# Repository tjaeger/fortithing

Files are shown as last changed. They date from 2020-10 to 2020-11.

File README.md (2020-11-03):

[Datasheet](/_asset/Datasheet.pdf)

[Schematics](/hardware/FortiThing%20v2.0%20rev.A%20SCHEMATICS.pdf)

[Docu on fortithing.readthedocs.io](https://fortithing.readthedocs.io/en/latest/)

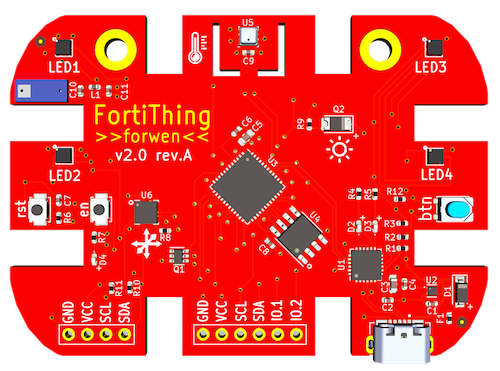
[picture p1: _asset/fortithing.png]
FortiThing


# FortiThing v2 

## Hardware

FortiThing is built around Espressif ESP32 MCU (ESP32-PICO-D4).
2MB integrated Flash, 32/64Mbit external QSPI Memory.

In addition it has a series of actors and sensors. Those are:
* IR/Light Sensor
* 3-Axis Accelerometer
* Temperature, Humidity, barometric pressure
* 4x programmable RGB-LED (LS8822/NS107)
* Capacitive-Touch sensor (back side)
* Tactile Button (front side)
* Exposed I2C Bus
* Exposed IO1/IO2 Pins

ESP32 Details
* Bluetooth
* WIFI (2.4Ghz)
* on-board 3D Antenna
* Dual Core Tensilica MCU
* Micropython, Arduino, native IDF and many more Environments
* 64Mbit QSPI RAM & 2MB integrated Flash

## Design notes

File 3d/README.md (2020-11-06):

This is an OpenSCAD design for a 3D protective case for FortiThing v2.
There is (currently) no lid to the box.

The STL was generated from OpenSCAD. It is provided here for people who can process .scad.

The protective enclosure was successfully printed on an Anet A8, with PLA.

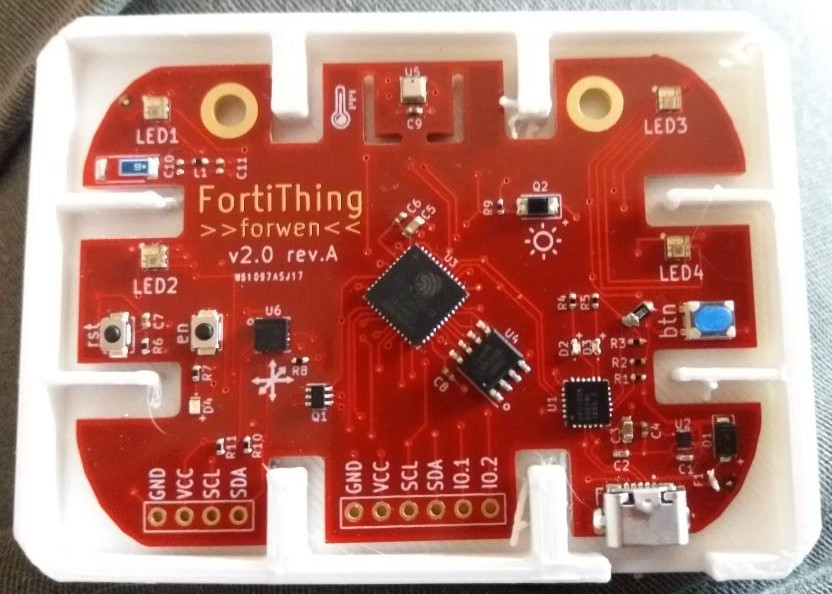
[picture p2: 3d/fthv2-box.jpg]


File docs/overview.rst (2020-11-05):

FortiThing Overview
-----------------------

The FortiThing Documentation Project is a community based documentation effort.
Goal is to document fundamentals, use cases and examples for various cases.
FortiThing is very flexible on how to be programmed, MicroPYTHON,
C++, Arduino/C to name a few.
It has WiFi and Bluetooth connectivity so it can talk to the World.

FortiThing is built to make this "IoT thing" more tangible and to have fun.
I wanted the programmability of a Microcontroller, the ease of Arduino or Python
the power of Internet connectivity - it should have Sensors and Actors. Last but not
least that thing has to be able to blink.

FortiThing is helping interested Audience and geeks to get a grasp on IoT.
It's a "fortified" shaped Microcontroller Platform with Sensors and Actors.

Repository can be found on [Github](https://github.com/tjaeger/fortithing.git)

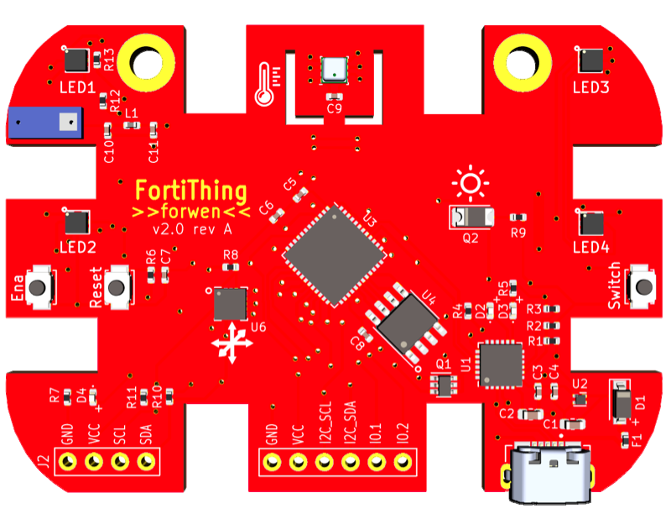
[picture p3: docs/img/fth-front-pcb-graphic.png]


Want to help ?
--------------

If you want to support the Project with contributing a use case or libraries or
apps or even documentation ?

- Developed a Demo for MS Azure integration ?
- Created a cool Demo to show IoT Security with FortiGate ?
- Built something useful with external stuff connected ?
- Missing something in the Docu and want to add ?

Let me know !

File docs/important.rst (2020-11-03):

Important notes
================

FortiThing has been design with care and is tolerant to many circumstances.
However basic measures should be applied and basic rules being followed to avoid damage to both FortiThing or connected Devices.

.. warning::
   It's unlikely you destroy the Hardware "easy" but the external IO nor other ports (eg USB) are ESD protected. It's recommended to apply basic ESD measure to avoid damage. For Example ground yourself (touch Laptop) before touching the board.

.. warning::
   It's unlikely you destroy the Hardware "easy" but the external IO nor other ports (eg USB) are ESD protected. It's recommended to apply basic ESD measure to avoid damage. For Example ground yourself (touch Laptop) before touching the board.

.. warning::
   3.3V Power on IO is directly connected to Main Power net off LDO. There is no Fuse. If you create a short-circuit it may damage the LDO or other components.

.. important::
   The main power (5V from USB) is protected with a PTC Fuse. A short on the board should not damage a connected Laptop.

.. important::
  You should not draw more than 30mA per GPIO from the external connectors as they’re directly connected to MCU. Drawing more may damage the MCU. Treat them as Digital-IO or low-power PWM.

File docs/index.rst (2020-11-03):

==========================================
Welcome to FortiThing Doc's documentation!
==========================================

.. toctree::
   :caption: Intro
   :maxdepth: 2

   important.rst
   overview

.. toctree::
   :caption: Hardware Details
   :maxdepth: 1

   /hwref/hwref
   /hwref/gpio

.. toctree::
   :caption: Getting started
   :maxdepth: 2

   /getstarted/index.rst

.. toctree::
   :caption: Arduino Toolchain
   :maxdepth: 2

   /arduino/arduino.rst

.. toctree::
   :caption: Micropython
   :maxdepth: 2

   /micropython/micropython.rst
   /micropython/firststeps.rst

.. toctree::
   :caption: License
   :maxdepth: 2

   license

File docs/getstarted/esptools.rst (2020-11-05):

Environment/ESPTools
---------------------

It makes sense to install a basic environment for tools like ESPTool, micropython and others. If you only plan to work with Arduino IDE this step can be skipped

# Virtualenv for Python

To not mess up your system Python environment it's recommened to install virtualenv.
Also istall a recent Version of python, 3.7/3.8 [#]_

`Python download from python.org <https://www.python.org/downloads/>`_

`virtualenv download from pypa.io <https://virtualenv.pypa.io/en/latest/installation.html>`_

Footnote 2 [#]_

.. code-block:: bash
   :emphasize-lines: 1, 7

   $ virtualenv -p python3.8 env38
   Running virtualenv with interpreter /Library/Frameworks/Python.framework/Versions/3.8/bin/python3.8
   Also creating executable in /private/tmp/env38/bin/python
   Installing setuptools, pip, wheel...
   done.

   $ source env38/bin/activate
   (env38) $ python -V
   Python 3.8.2

Install ESPTools directly
-------------------------

.. code-block:: bash

   (env38) $ pip install esptools
   [...]
   (env38) $ esptool.py version‚

.. note::

   ESPTools are needed to flash Firmware (unless you use Arduino) to FortiThing. For Example if you need to flash Micropython Firmware.

Install ESPTools in Docker
-------------------------

.. code-block:: bash

$ docker pull espressif/idf:latest
Status: Downloaded newer image for espressif/idf:latest
docker.io/espressif/idf:latest

.. note::

This pulls "latest" IDF. You also can specify a specific Version, see https://hub.docker.com/r/espressif/idf/tags
for available images.

.. [#] Footnote test.
.. [#] Footnote2 test.

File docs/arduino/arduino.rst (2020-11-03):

Arduino
===========

Installation Arduino
------------------------

This chapter still needs to be done. Really.

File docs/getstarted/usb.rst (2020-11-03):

Basic connectivity
-------------------

Typically you'll connect to FortiThing by USB. It uses a CP2102N Chipset for USB->UART which you need to install the VCP drivers for. The CP2102N is a very well supported Chip and provides Drivers for all major OS and also is quick in updates for new OS Releases.

`Download Silabs CP2102N Driver <https://www.silabs.com/products/development-tools/software/usb-to-uart-bridge-vcp-drivers>`_

Once driver has been installed and you plug in FortiThing you should see it recognised:

**Linux/OSX**

.. code-block:: bash 

   $ ls /dev/cu*
   /dev/cu.SLAB_USBtoUART

**Windows**

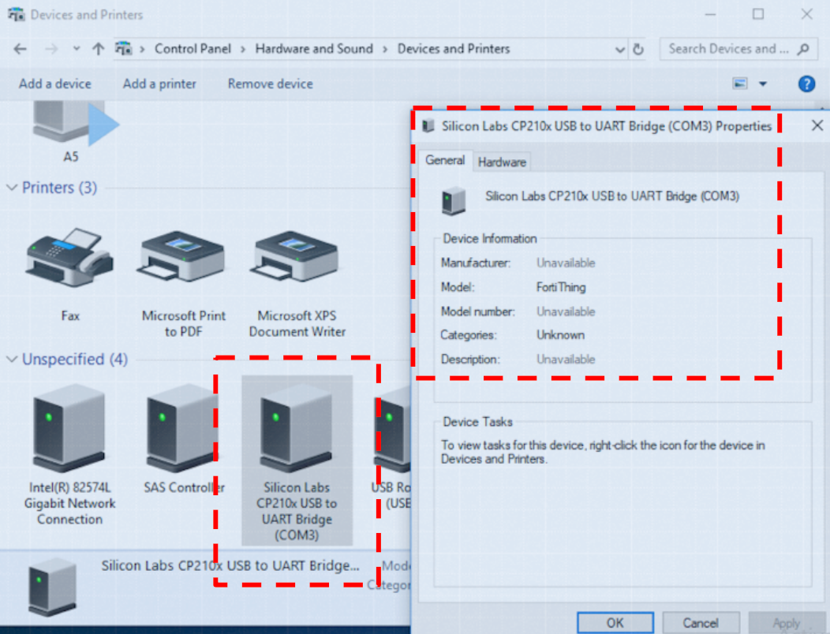
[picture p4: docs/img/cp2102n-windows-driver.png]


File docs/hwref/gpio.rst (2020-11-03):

GPIO Details
===============

This is a graphical overview of the IO Ports which are exposed or being used internally.
It contains the User defined IO Ports as well as the MCU ports for other Services.
eg the MCU ports for I2C-Bus, RGB LED Bus, integrated LED and Switches.

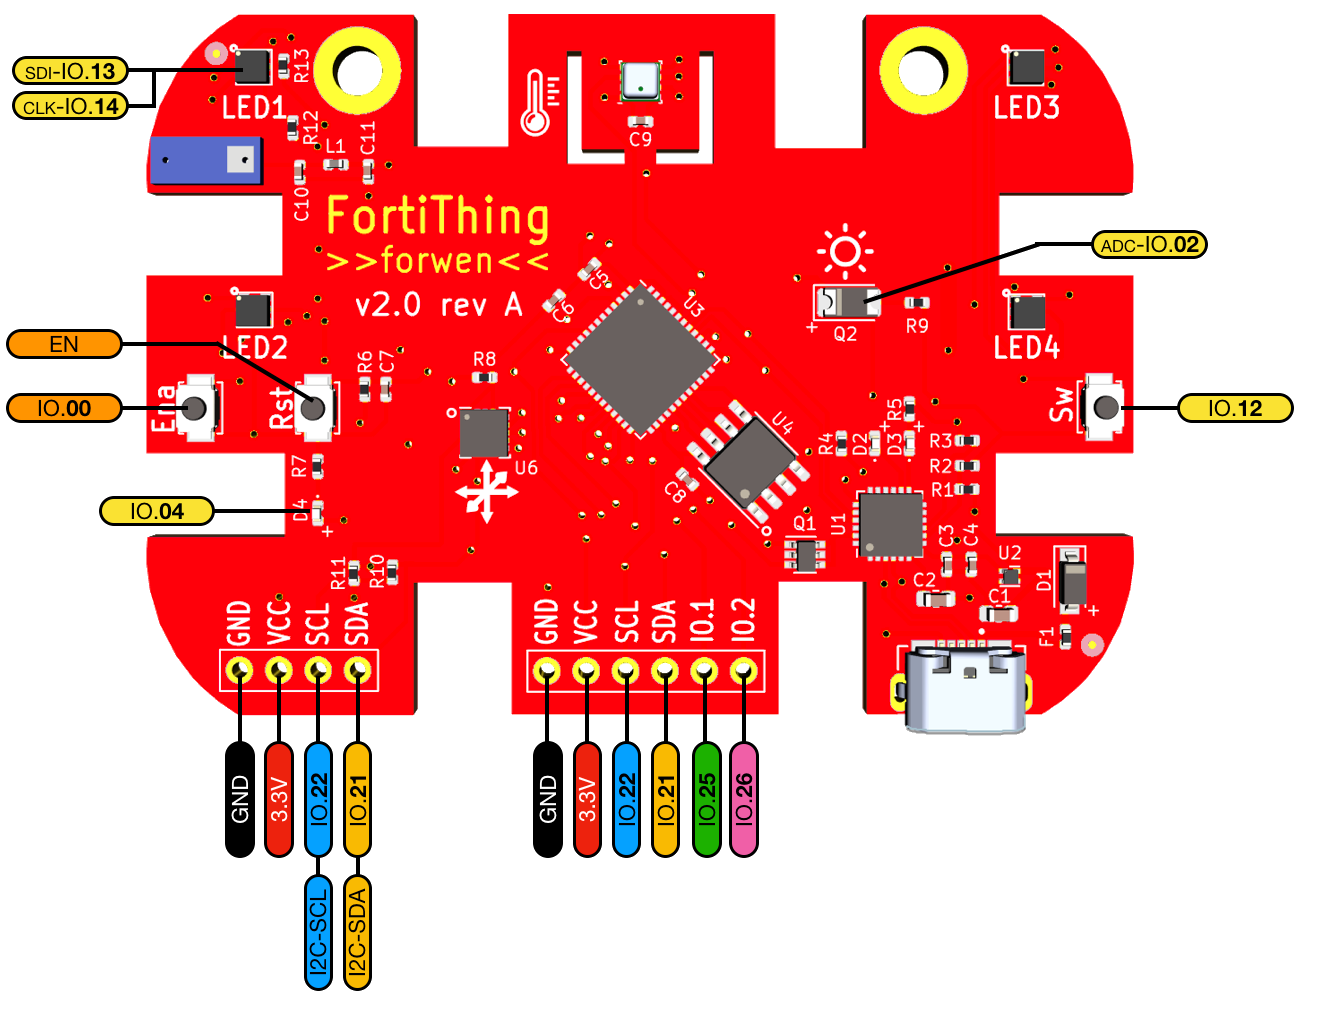
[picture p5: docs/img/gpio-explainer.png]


I2C Bus
-------------

BME280, LISDH30 and optionally OLED Displays are hooked up to a I2C Bus.

Predefined Addresses are:

- BME280, ``0x77``
- LISDH30, ``0x18``
- OLED, typically ``0x3c`` for those ssd1306 OLED

.. note::
   The I2C Bus is internally terminated with 4.7k Ohm. If you hook up external I2C Slaves make sure they don't have another set of pull-up resistors.

External Pin Headers
----------------------

There are 2 rows of external connectors. You can solder Pin Headers to those if you want. They use a standard of 0.54mm pitch and 1mm drill.

# Bottom left section, 4 pins (aka OLED-connector)
# Bottom mid section, 6 pins

The "OLED-connector" has GND/VCC(3.3V) and SCL(I2C), SCA(I2C), exposed. The Layout is typically found on those lower cost "aliexpress" OLED Boards, 0.96"/1.2" OLED and can be directly soldered or via female Headers.

The mid section IO Ports have GND/VCC/SCL/SCA and IO.1/IO.2 exposed. 
IO.1 and IO.2 are connected to Port-25 and Port-26 respectively on the ESP32 Chip.

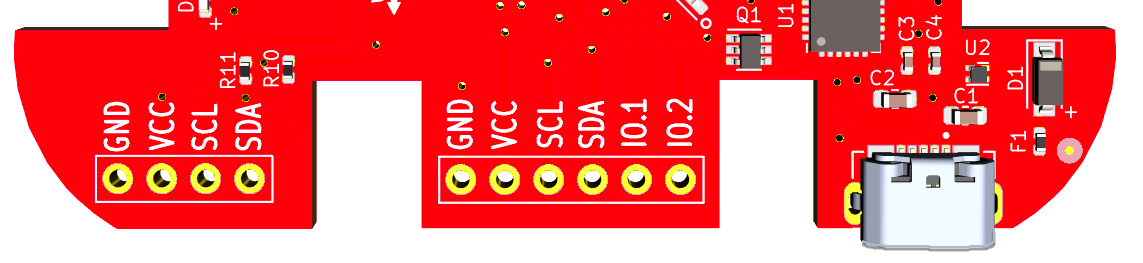
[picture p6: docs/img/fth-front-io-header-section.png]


.. warning::
   The external IO nor other ports (eg USB) are ESD protected. It's recommended to apply basic ESD measure to avoid damage. For Example ground yourself (touch Laptop) before touching the board.

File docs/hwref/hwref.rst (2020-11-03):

FortiThing Hardware Reference
===============================

- **Fortified PCB Layout**
- **65mm x 45mm**

Hardware Design in Detail
-------------------------

**Espressif ESP32 Pico D4 SIP**
   - ESP32 SoC
   - 4MB integrated Flash
   - internal oscillator
   - RF Module
   - 7mm x7mm QFN
   - Dual-Core Tensilica Xtensa LX6 32bit Microprocessor
   - 802.11 b/g/n Wireless 
   - Bluetooth v4.2 (BR/EDR and BT LE support)

**Interfaces:** 
   - UART, SPI, I2C
   - ADC, DAC, PWM

`ESP32 Datasheet <https://www.espressif.com/sites/default/files/documentation/esp32-pico-d4_datasheet_en.pdf>`_

Sensors
-------

**Environmental Sensor**

- ME280 / Bosch 
- Temperature
- relative Humidity
- Barometric Pressure
- I2C/SPI Interface
- 2.5x2.5x0.93mm Package

`Bosch BME280 Datasheet <https://www.bosch-sensortec.com/media/boschsensortec/downloads/datasheets/bst-bme280-ds002.pdf>`_

**Luminosity Sensor**

- IR Spectrum focus
- analog measurement, ADC converts to 16bit output
- peak detection is at 940nm (IR). Range is 730-1100nm

**3-Axis Accelerometer**

- LIS3DHTR / STMicro
- Three axis sensing
- I2C/SPI Interface
- Free-fall detection 
- click/double-click detection
- Interrupt output
- 3x3x1mm LGA-16 Package

`STM LIS3DH Datasheet <https://www.st.com/content/ccc/resource/technical/document/datasheet/3c/ae/50/85/d6/b1/46/fe/CD00274221.pdf/files/CD00274221.pdf/jcr:content/translations/en.CD002742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>`_

Actors
------

**RGB LED**

FortiThing has a total of 4 programmable RGB LEDs.
Utilisig the new NS107S 2020 LED. The LED can be used with the FastLED Library for Example within the Arduino Framework. 

**User progammable Switch**

- There is 1 main programmable tactile switch (SW). The 2nd one is "Ena" - however this has a special function during booting and should be used with care.
- On the backside of the board there is a "touch sensor" (capcitive touch sensor)

**mini LED (Blue)**

Another small (blue) LED is on-board which is user controlled. It can be used as additional LED.

Components Map
--------------

You may find this useful to quickly understand what is located where.
Hic sunt dracones.

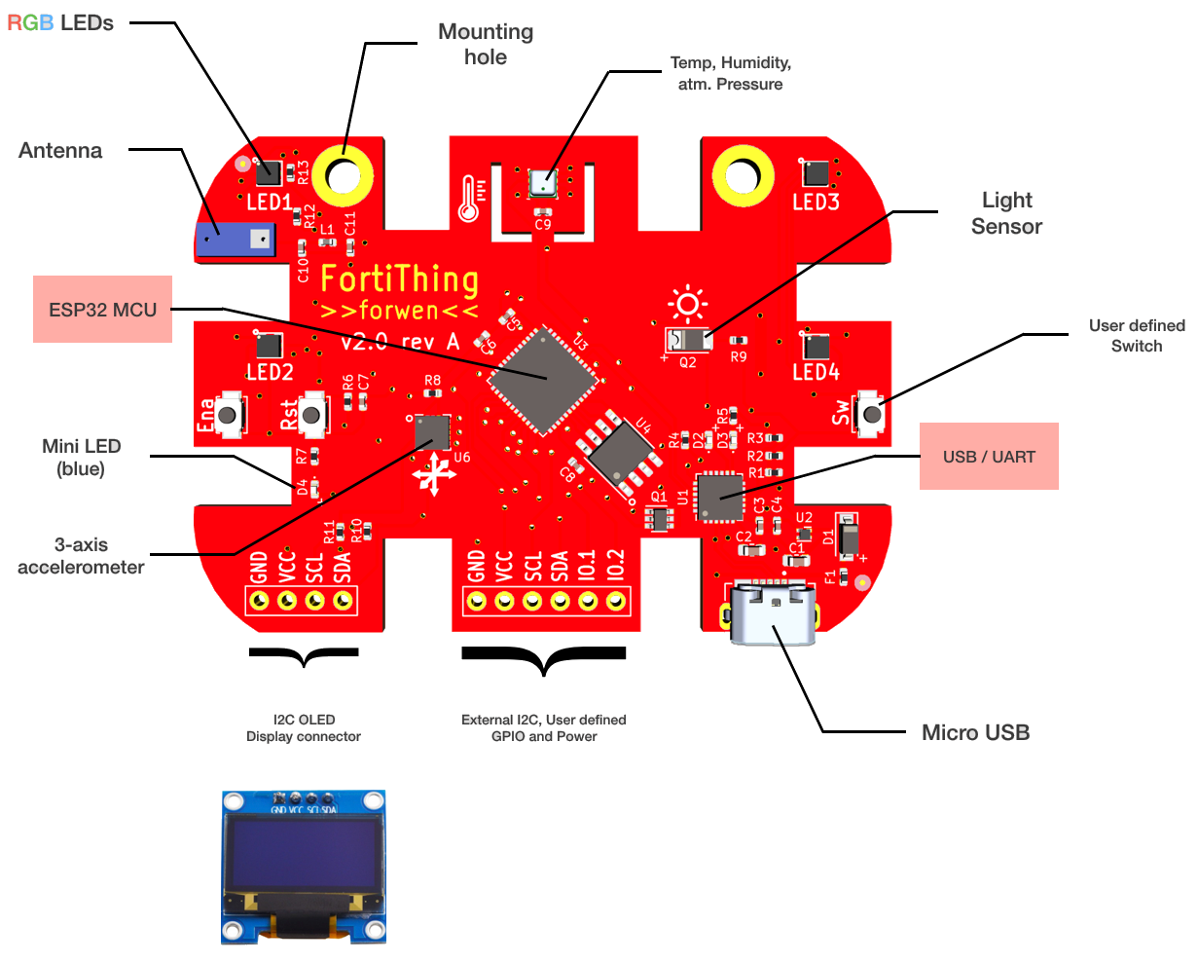
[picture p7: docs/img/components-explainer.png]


FortiThing schematics
---------------------

Schematics :download:`pdf <../img/schematics.pdf>`

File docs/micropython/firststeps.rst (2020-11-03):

Say 'hello' 
------------

.. code-block:: bash 

   (ENV38) $ rshell -p /dev/cu.SLAB_USBtoUART
   > repl
   Entering REPL. Use Control-X to exit.
   repl_serial_to_stdout dev = <rshell.main.DeviceSerial object at 0x102c7e908>>
   >>> help()
   [...]
   >>> print ("Hello FortiThing!")
   Hello FortiThing!

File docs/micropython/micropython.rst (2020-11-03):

MicroPYTHON
===========

.. note:: 

   This assumes you have a virtualenv/Python and ESPTools installed and you are within a virtualenv environment. 

Tools Installation
------------------

Please install some tools to interact with Micropython once installed.
If using ``virtualenv`` make sure you perform this from within.

.. code-block:: bash 

   (ENV38) $ pip3 install rshell 

More Infos on rshell, visit  
`rshell on github <https://github.com/dhylands/rshell>`_

Verify Installation

.. code-block:: bash 

   (ENV38) $ rshell --version

Flashing Micropython 
--------------------

Download Micropython from https://micropython.org/download 
for the ESP32 Platform (GENERIC).
`Github Link for Source and Docs  <https://github.com/micropython/micropython>`_

At the time of writing this is `Micropython 1.12 <https://micropython.org/resources/firmware/esp32-idf3-20191220-v1.12.bin>`_

Flash the downloaded Micropython Firmware to FortiThing:

.. code-block:: bash 

   (ENV38) $ esptool.py --chip esp32 --port /dev/ttyUSB0 --baud 460800 --erase-all write_flash -z 0x1000 esp32-idf3-20191220-v1.12.bin

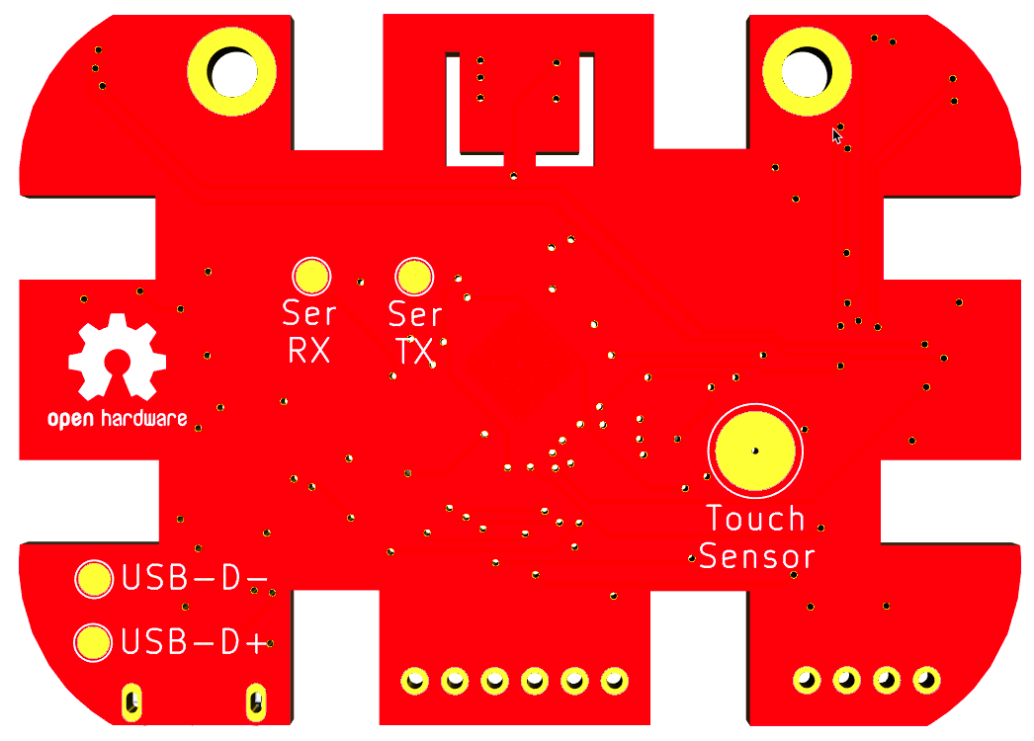
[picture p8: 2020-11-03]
docs/img/fth-back-pcb-graphic.png

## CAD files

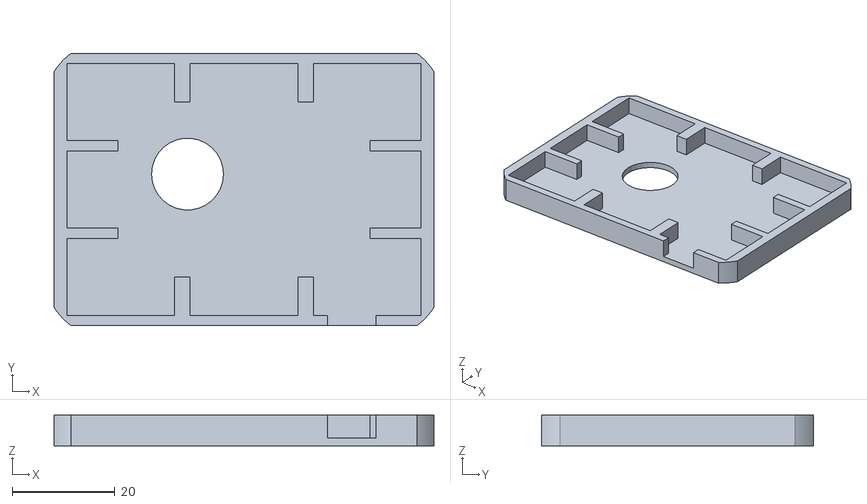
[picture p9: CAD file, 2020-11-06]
3d/fortithing-v2.stl
74.0 x 53.0 x 6.00

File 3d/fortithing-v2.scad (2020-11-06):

// size of the PCB - the +x are for printing margins
fth_length=68+2; 
fth_width=48+1;

// size of the 3D box
box_x = fth_length + 4;
box_y = fth_width + 4;
box_z = 6;


// it's a cube from which we remove 9 identical smaller cubes "noeuds"
// and one central cube.
difference() {
    cube([box_x, box_y, box_z], true);
    noeuds();
    central();
    usbAlim();
    touchSensor();
    roundedCorners();
}

// the PCB roughly has 9 cubes (3x3) which are joined together
module noeuds() {
    for (i = [-24:24:25 ]) {
        for (j = [-17: 17: 17] ) {
            translate([i, j, 1])  cube([18+3,12+3, box_z-1], true);
        }
    }
}

module central() {
    // cube central
    translate([0,0,1]) cube([45+4,30+4,box_z-1], true);   
}

// removes space for the USB power
module usbAlim() {
    color("red") translate([21, -20, 1]) cube([9.5,15, box_z-1], true);
}

// removes space to be able to access the touch sensor behind the PCB
module touchSensor() {
    color("blue") translate([-11, 3, -box_z]) linear_extrude(height=box_z+10) circle(r=7, $fn=30);
}

// just for a nicer look
module roundedCorners() {
    difference() {
        cube([box_x+5,box_y+5,box_z+10], true);
        
        for (i=[-26:52:32]) {
            for (j= [-16:32:25]) {
                translate([i, j,-1]) cylinder(h=box_z+20, r=13, $fn=300, center=true);
            }
        }
        cube([54+3, 52+3, box_z+20], center=true);
        cube([72+3, 32+3, box_z+20], center=true);

    }
}

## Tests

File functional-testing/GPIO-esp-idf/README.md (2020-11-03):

# GPIO tests with esp-idf SDK

The esp-idf SDK from Espressif allow you to go deeper with the ESP32. The code is low level and allow you to control everything in the chip. The drawback is it's slightly more complex than using the Arduino IDE.

## The environment
First, setup the SDK under your favourite OS: [Link to the Espressif web site](https://docs.espressif.com/projects/esp-idf/en/latest/esp32/get-started/index.html)
Tested successfully under Linux and Windows with the Fortithing. Even with VM in Virtualbox plus USB passthrough to flash the device.

## Your first own code
The idea is to start from the `hello_world` from [step 5](https://docs.espressif.com/projects/esp-idf/en/latest/esp32/get-started/index.html#step-5-start-a-project). 
Copy again the template and copy the GPIO.c + CMakeLists.txt files in the folder `main`.
To use the full flash, change the default size: run `idf.py menuconfig` go to `Serial flasher config` and set the `Flash size` to `4 MB`.
Compile and flash the board and that's it.

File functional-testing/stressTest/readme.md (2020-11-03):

# StressTest app for the Fortithing board

The goal of the project is to test during hours and days the board to validate the hardware.

## How it works
The board boot, hook on the local 2.4GHZ WPA/WPA2 Wifi and get it's IP from the DHCP server.
The board send to the server, via a GET request, the asked sensor values by the server. From the server's reply, the board keep the next sensor to send, shift the 4 RGB LED and pause for 1 second.

## Deploy it

### The board
Before flashing the board, 3 steps are needed:
 - Install the lib: FastLED, Adafruit LIS3DH, Adafruit BMP280 Library (and their dependencies)
 - Modify the 4 #define at the beginning of stressTestFortithing.ino file to setup your Wifi and server settings
 - Patch the Adafruit BMP280 lib to read correctly the BMP280 sensor:
Open this file https://github.com/adafruit/Adafruit_BMP280_Library/blob/master/Adafruit_BMP280.cpp
comment those 2 lines:               
 99:   if (read8(BMP280_REGISTER_CHIPID) != chipid)             
100:    return false;                

### The server
PHP need to be installed, create a folder "file" at the root of the server, copy file.php and do the corresponding setting asked for stressTestFortithing.ino.
Do not forget to set the folder writeable for the PHP code.
2 files are generated server side, in CSV format, with the content of the accelerometer and temperature sensors. So you can check the data in a worksheet by graph them and see if everything is accurate.

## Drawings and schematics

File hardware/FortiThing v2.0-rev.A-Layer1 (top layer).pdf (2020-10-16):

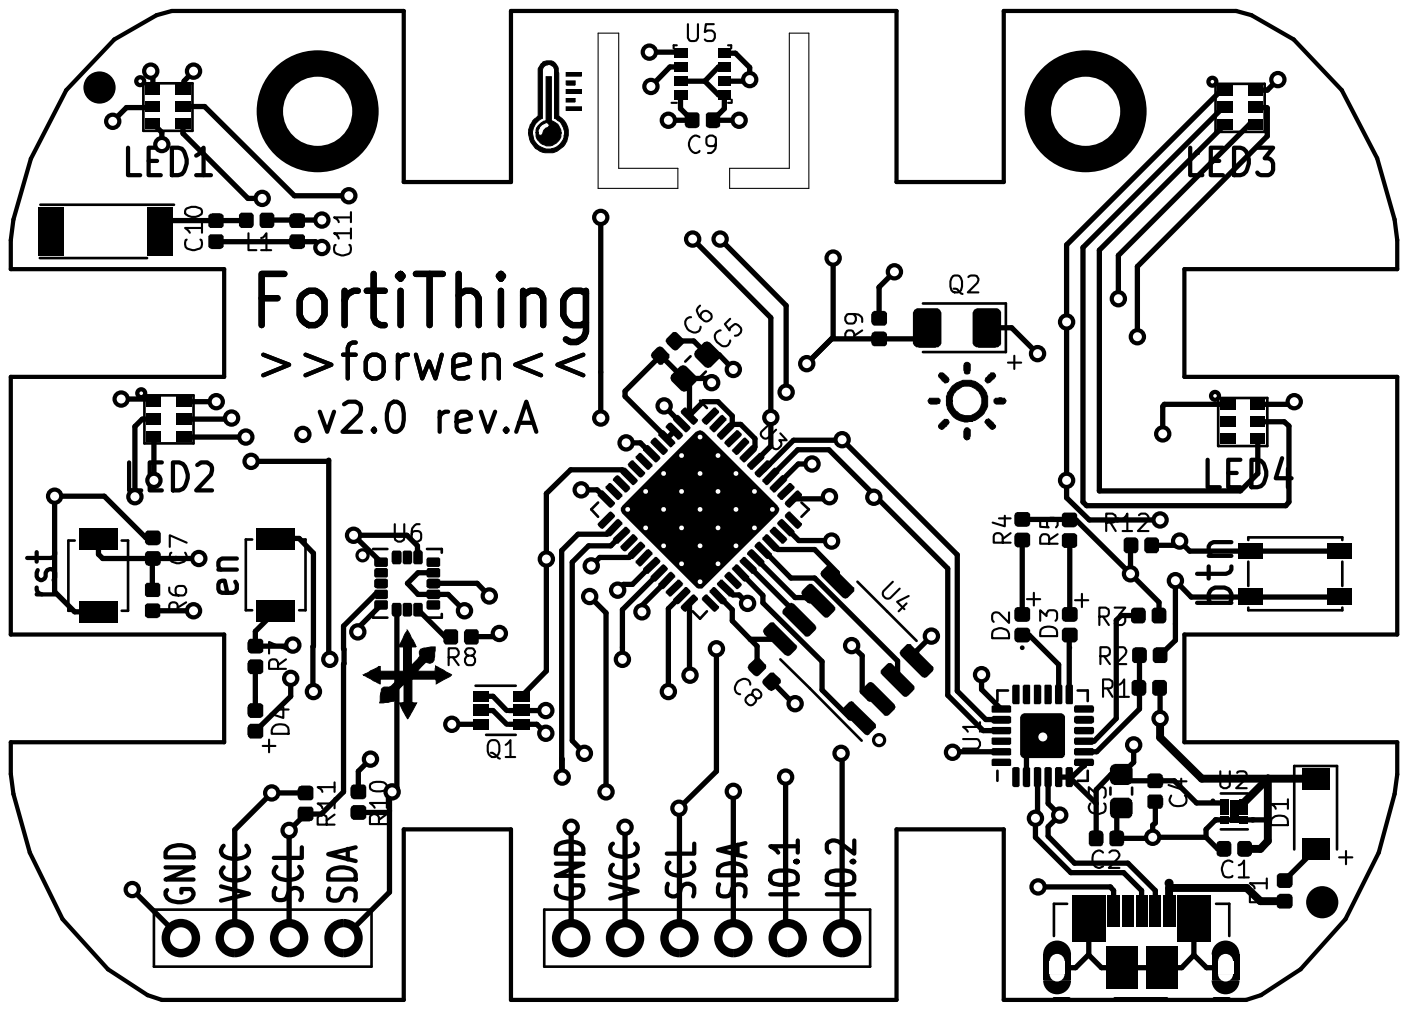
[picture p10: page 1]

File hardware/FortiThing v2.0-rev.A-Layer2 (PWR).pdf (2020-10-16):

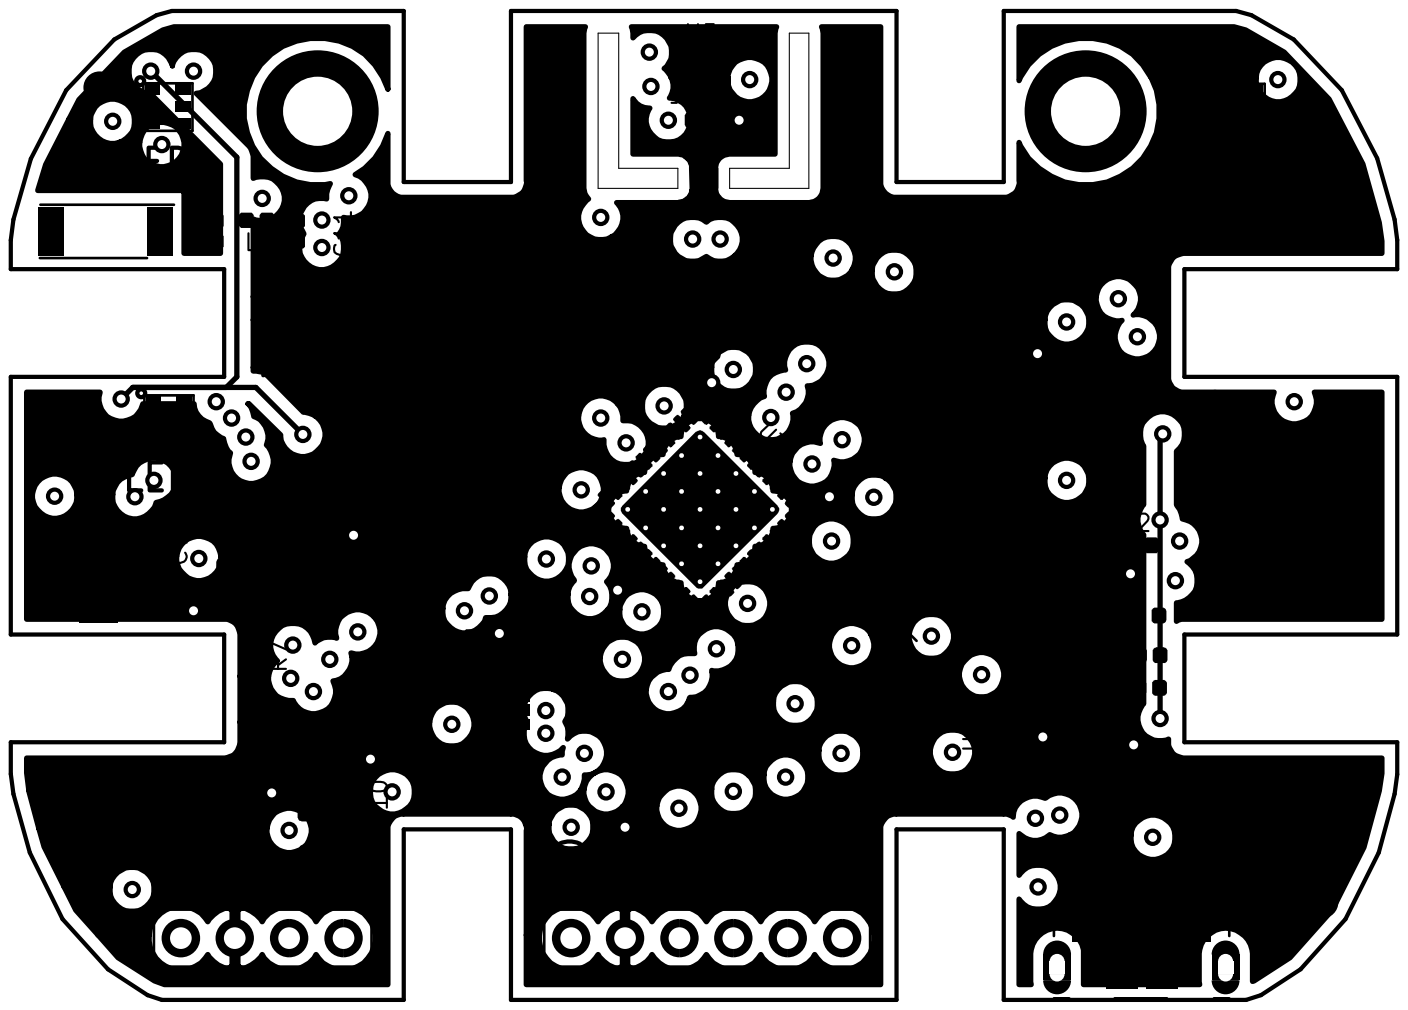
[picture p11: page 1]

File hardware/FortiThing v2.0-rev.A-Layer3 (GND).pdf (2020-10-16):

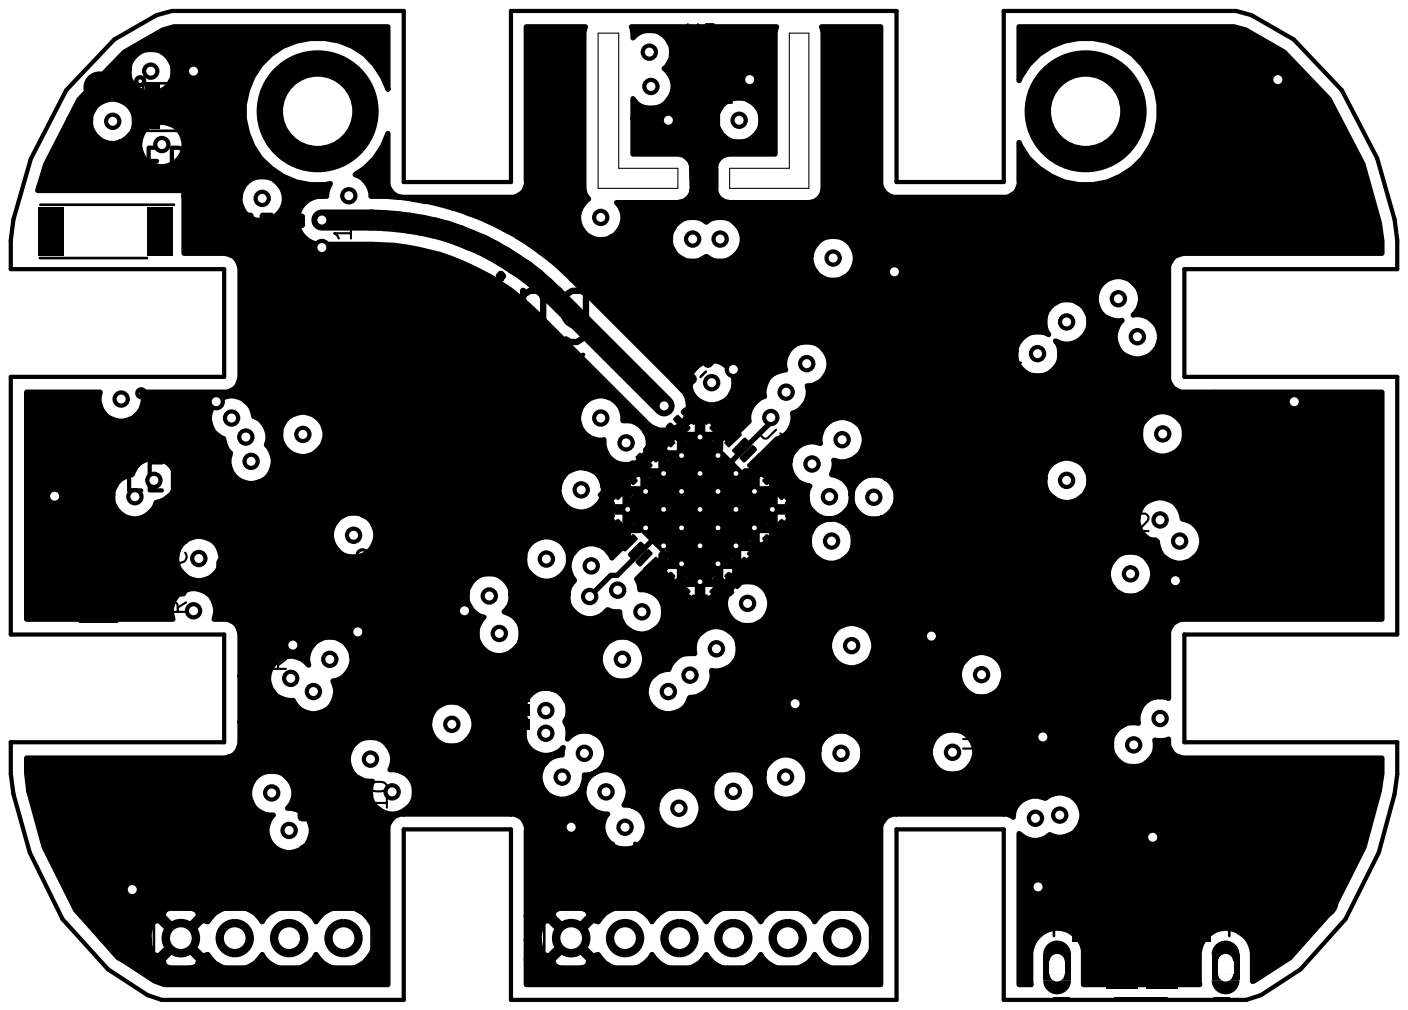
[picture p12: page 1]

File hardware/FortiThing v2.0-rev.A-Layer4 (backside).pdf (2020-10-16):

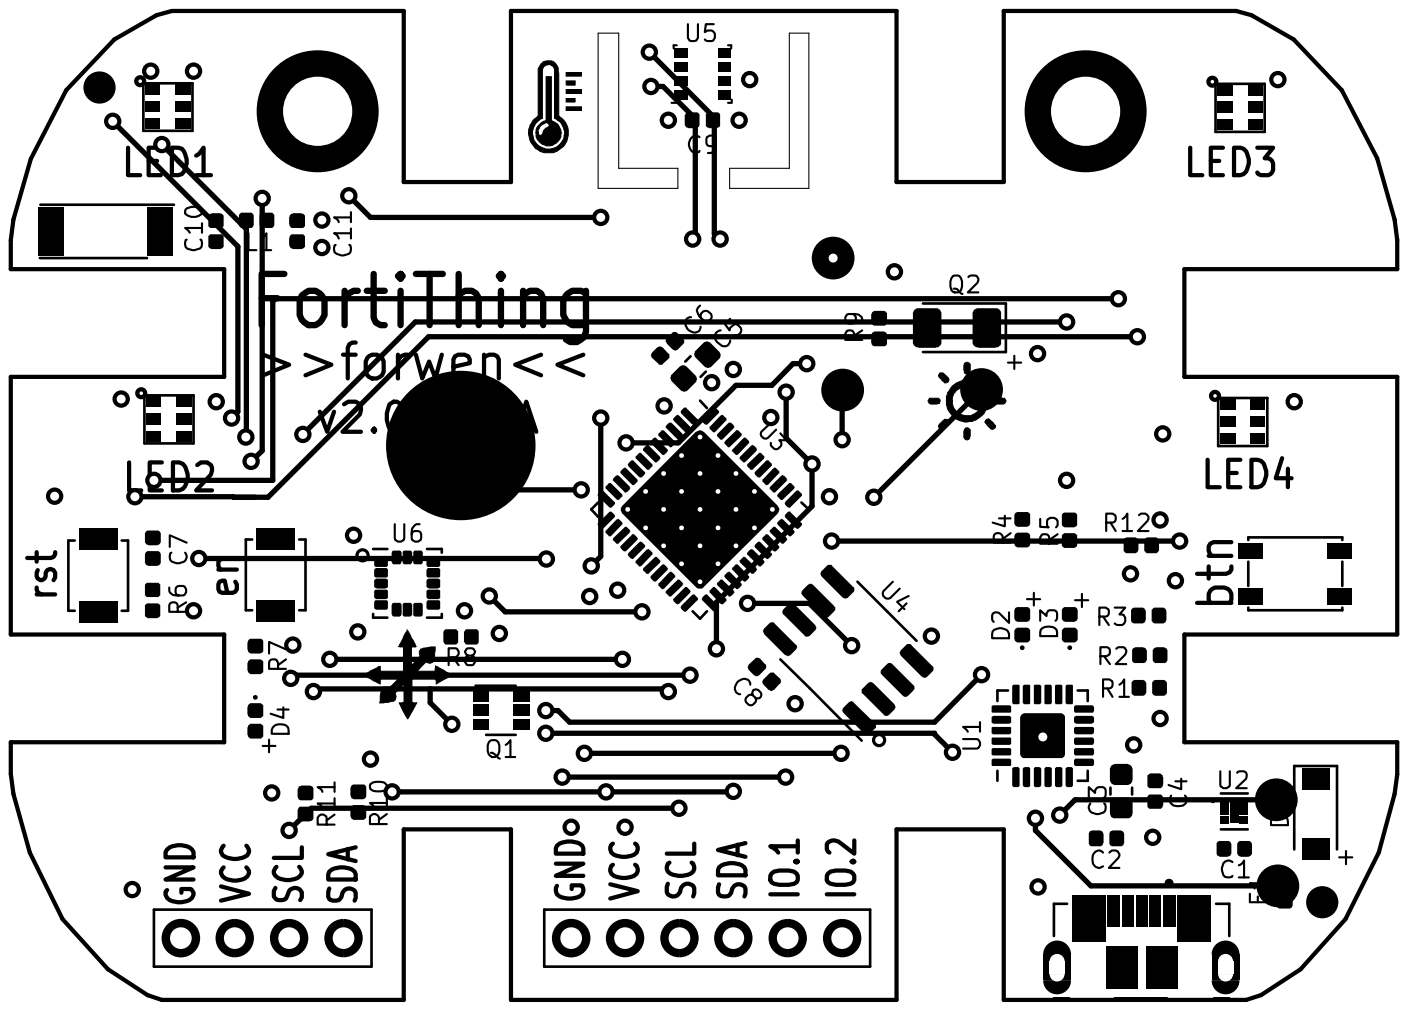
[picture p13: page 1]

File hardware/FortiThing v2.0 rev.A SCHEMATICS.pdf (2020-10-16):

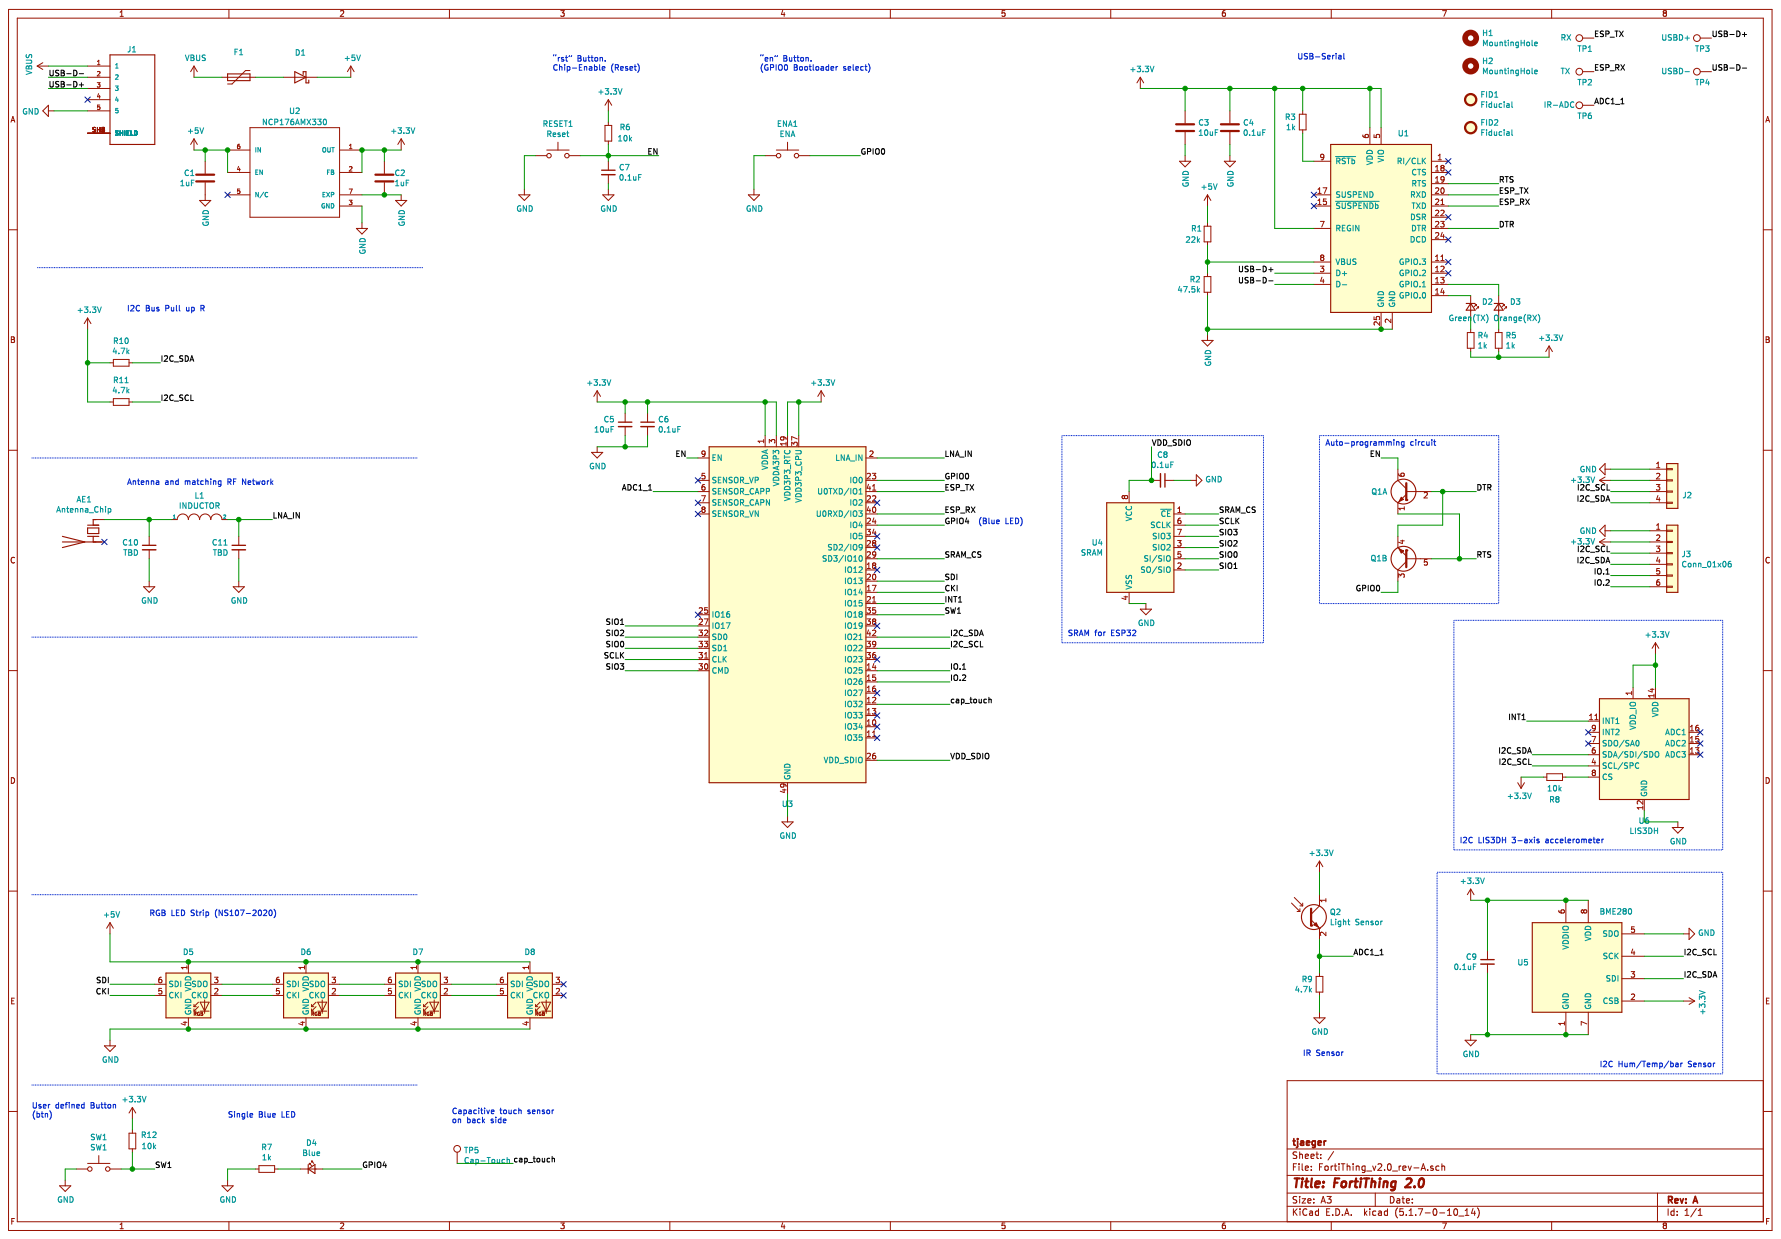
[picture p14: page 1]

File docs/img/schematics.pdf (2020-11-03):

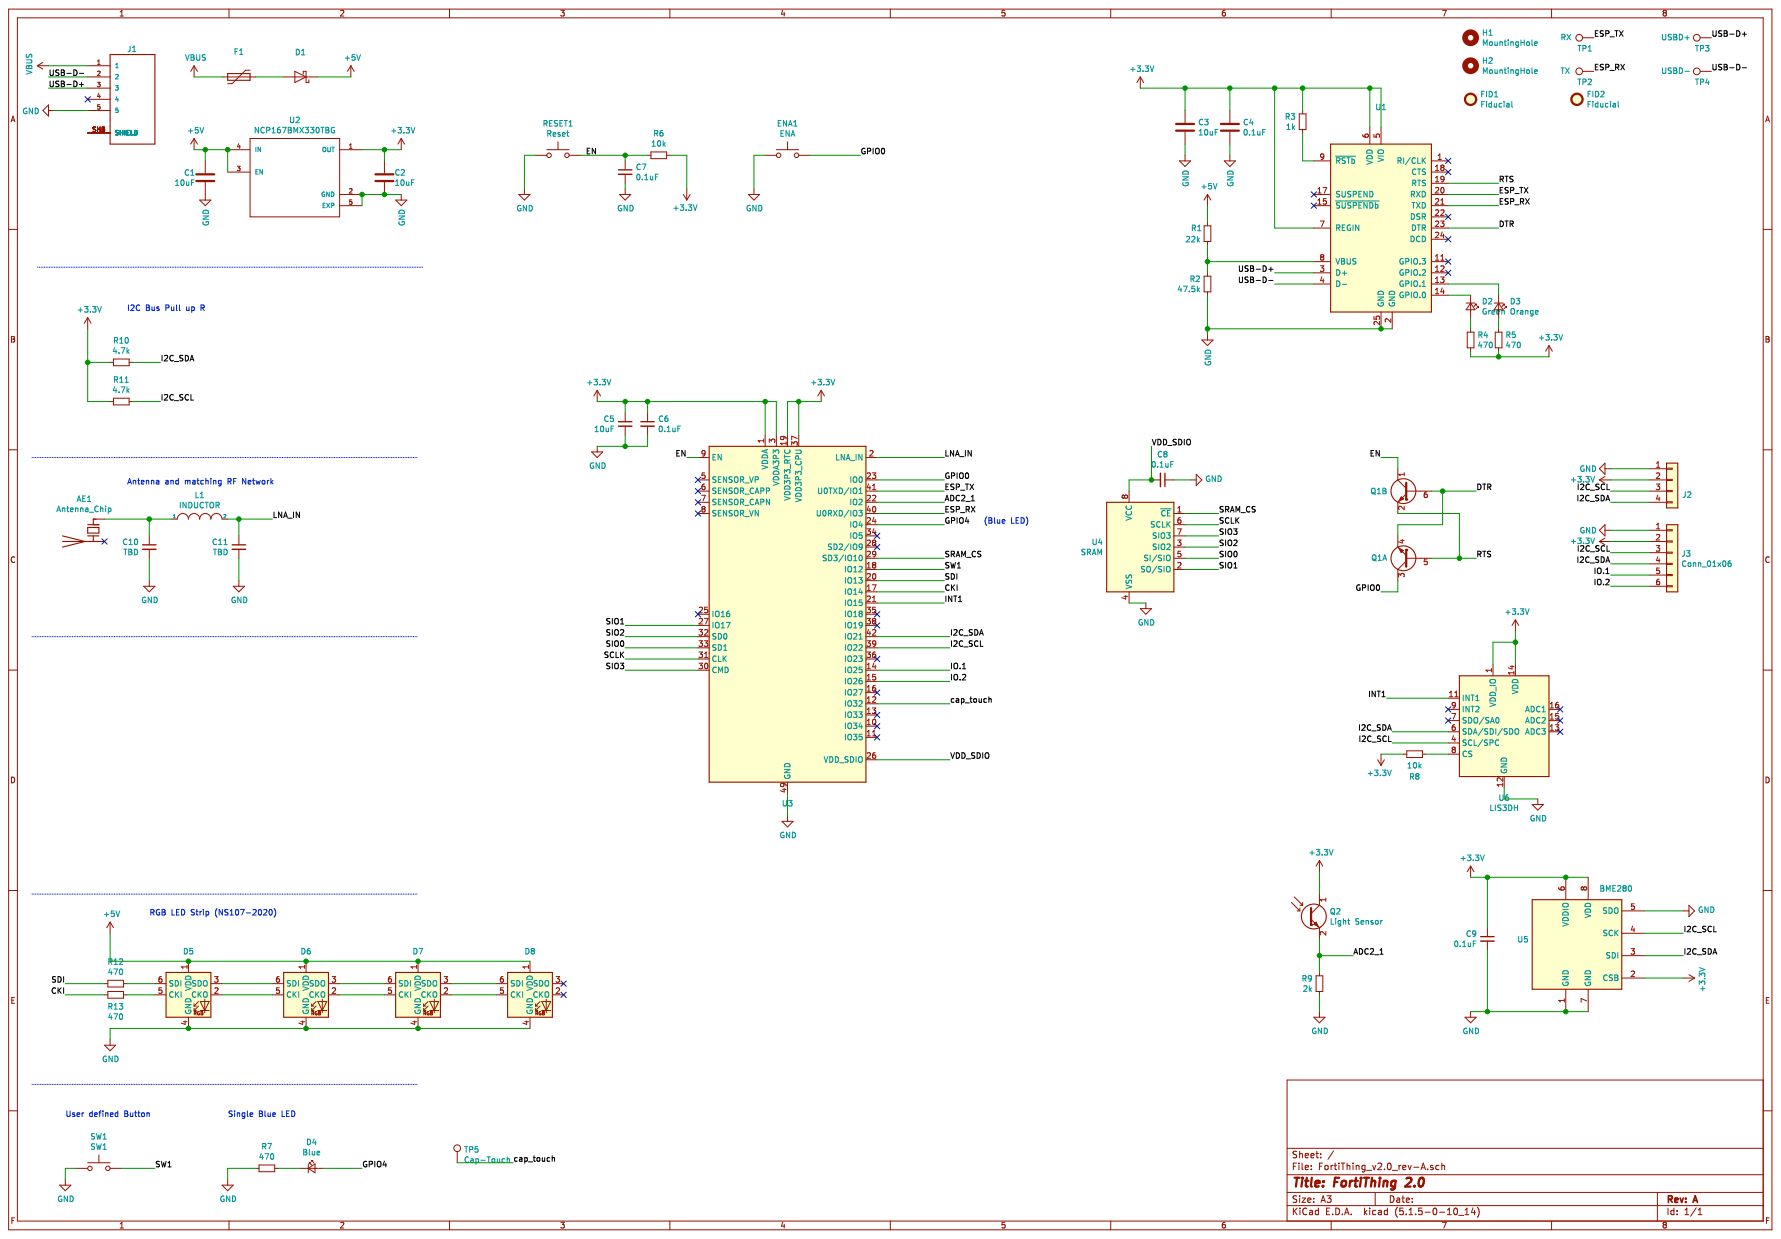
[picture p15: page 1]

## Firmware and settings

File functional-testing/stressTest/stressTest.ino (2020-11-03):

/**
 * StressTest for Fortithing V2 board
 * 
 * Phil 2020/10/31
 *
 */

//define

#define WIFI_SSID "Your2.4GHZSSID"
#define WIFI_PASSWORD "YourWPA/WPA2Password"
#define SERVER "192.168.0.23"
#define PATH "/file/file.php"


//needed lib: FastLED, Adafruit LIS3DH, Adafruit BMP280 Library 

// WARNING: after installing libs, patch Adafruit BMP280 LIB to correctly read the BMP280
// Open this file https://github.com/adafruit/Adafruit_BMP280_Library/blob/master/Adafruit_BMP280.cpp
// comment those 2 lines:
// 99:   if (read8(BMP280_REGISTER_CHIPID) != chipid)
//100:    return false;

//serial
#include <Arduino.h>
#define USE_SERIAL Serial

//Wifi+http
#include <WiFi.h>
#include <WiFiMulti.h>
#include <HTTPClient.h>

//Accelerometer
#include <Wire.h>
//#include <SPI.h>
#include <Adafruit_LIS3DH.h>
#include <Adafruit_Sensor.h>

//LED
#include <FastLED.h>

//Temp
//#include <Wire.h>
//#include <SPI.h>
#include <Adafruit_BMP280.h>


//Wifi
WiFiMulti wifiMulti;

//Accelerometer
Adafruit_LIS3DH lis = Adafruit_LIS3DH();
sensors_event_t event;

//LED
#define DATA_PIN 13
#define CLOCK_PIN 14
// #define DATA_PIN 23
// #define CLOCK_PIN 22
#define NUM_LEDS    4
#define BRIGHTNESS  80
#define LED_TYPE    APA102
#define COLOR_ORDER GRB
CRGB leds[NUM_LEDS];
CRGBPalette16 currentPalette;
TBlendType    currentBlending;

extern CRGBPalette16 myRedWhiteBluePalette;
extern const TProgmemPalette16 myRedWhiteBluePalette_p PROGMEM;

#define UPDATES_PER_SECOND 1

//Temp
Adafruit_BMP280 bmp; // use I2C interface
Adafruit_Sensor *bmp_temp = bmp.getTemperatureSensor();
Adafruit_Sensor *bmp_pressure = bmp.getPressureSensor();

void setupTemp() {
  USE_SERIAL.println(F("BMP280 Sensor event test"));

  if (!bmp.begin(0x76)) {
    USE_SERIAL.println(F("Could not find a valid BMP280 sensor, check wiring!"));
    return;
  }

  /* Default settings from datasheet. */
  bmp.setSampling(Adafruit_BMP280::MODE_NORMAL,     /* Operating Mode. */
                  Adafruit_BMP280::SAMPLING_X2,     /* Temp. oversampling */
                  Adafruit_BMP280::SAMPLING_X16,    /* Pressure oversampling */
                  Adafruit_BMP280::FILTER_X16,      /* Filtering. */
                  Adafruit_BMP280::STANDBY_MS_500); /* Standby time. */

  bmp_temp->printSensorDetails();
}

void setupLED() {
    FastLED.addLeds<LED_TYPE, DATA_PIN, CLOCK_PIN, COLOR_ORDER>(leds, NUM_LEDS).setCorrection( TypicalLEDStrip );
    FastLED.setBrightness(  BRIGHTNESS );
    
    currentPalette = RainbowColors_p;
    currentBlending = LINEARBLEND;
}

void setupAccelerometer() {
  
  USE_SERIAL.println("LIS3DH test!");

  if (! lis.begin(0x19)) {   // change this to 0x19 for alternative i2c address
    USE_SERIAL.println("Couldnt start");
    while (1) yield();
  }
  USE_SERIAL.println("LIS3DH found!");

  lis.setRange(LIS3DH_RANGE_4_G);   // 2, 4, 8 or 16 G!

  USE_SERIAL.print("Range = "); Serial.print(2 << lis.getRange());
  USE_SERIAL.println("G");

  // lis.setDataRate(LIS3DH_DATARATE_50_HZ);
  USE_SERIAL.print("Data rate set to: ");
  switch (lis.getDataRate()) {
    case LIS3DH_DATARATE_1_HZ: USE_SERIAL.println("1 Hz"); break;
    case LIS3DH_DATARATE_10_HZ: USE_SERIAL.println("10 Hz"); break;
    case LIS3DH_DATARATE_25_HZ: USE_SERIAL.println("25 Hz"); break;
    case LIS3DH_DATARATE_50_HZ: USE_SERIAL.println("50 Hz"); break;
    case LIS3DH_DATARATE_100_HZ: USE_SERIAL.println("100 Hz"); break;
    case LIS3DH_DATARATE_200_HZ: USE_SERIAL.println("200 Hz"); break;
    case LIS3DH_DATARATE_400_HZ: USE_SERIAL.println("400 Hz"); break;

    case LIS3DH_DATARATE_POWERDOWN: USE_SERIAL.println("Powered Down"); break;
    case LIS3DH_DATARATE_LOWPOWER_5KHZ: USE_SERIAL.println("5 Khz Low Power"); break;
    case LIS3DH_DATARATE_LOWPOWER_1K6HZ: USE_SERIAL.println("16 Khz Low Power"); break;
  }
}

void setupWifi() {
    wifiMulti.addAP(WIFI_SSID, WIFI_PASSWORD);
}


void FillLEDsFromPaletteColors( uint8_t colorIndex)
{
    uint8_t brightness = 255;
    
    for( int i = 0; i < NUM_LEDS; i++) {
        leds[i] = ColorFromPalette( currentPalette, colorIndex, brightness, currentBlending);
        colorIndex += 3;
    }
}


// There are several different palettes of colors demonstrated here.
//
// FastLED provides several 'preset' palettes: RainbowColors_p, RainbowStripeColors_p,
// OceanColors_p, CloudColors_p, LavaColors_p, ForestColors_p, and PartyColors_p.
//
// Additionally, you can manually define your own color palettes, or you can write
// code that creates color palettes on the fly.  All are shown here.

void ChangePalettePeriodically()
{
    uint8_t secondHand = (millis() / 1000) % 60;
    static uint8_t lastSecond = 99;
    
    if( lastSecond != secondHand) {
        lastSecond = secondHand;
        if( secondHand ==  0)  { currentPalette = RainbowColors_p;         currentBlending = LINEARBLEND; }
        if( secondHand == 10)  { currentPalette = RainbowStripeColors_p;   currentBlending = NOBLEND;  }
        if( secondHand == 15)  { currentPalette = RainbowStripeColors_p;   currentBlending = LINEARBLEND; }
        if( secondHand == 20)  { SetupPurpleAndGreenPalette();             currentBlending = LINEARBLEND; }
        if( secondHand == 25)  { SetupTotallyRandomPalette();              currentBlending = LINEARBLEND; }
        if( secondHand == 30)  { SetupBlackAndWhiteStripedPalette();       currentBlending = NOBLEND; }
        if( secondHand == 35)  { SetupBlackAndWhiteStripedPalette();       currentBlending = LINEARBLEND; }
        if( secondHand == 40)  { currentPalette = CloudColors_p;           currentBlending = LINEARBLEND; }
        if( secondHand == 45)  { currentPalette = PartyColors_p;           currentBlending = LINEARBLEND; }
        if( secondHand == 50)  { currentPalette = myRedWhiteBluePalette_p; currentBlending = NOBLEND;  }
        if( secondHand == 55)  { currentPalette = myRedWhiteBluePalette_p; currentBlending = LINEARBLEND; }
    }
}

// This function fills the palette with totally random colors.
void SetupTotallyRandomPalette()
{
    for( int i = 0; i < 16; i++) {
        currentPalette[i] = CHSV( random8(), 255, random8());
    }
}

// This function sets up a palette of black and white stripes,
// using code.  Since the palette is effectively an array of
// sixteen CRGB colors, the various fill_* functions can be used
// to set them up.
void SetupBlackAndWhiteStripedPalette()
{
    // 'black out' all 16 palette entries...
    fill_solid( currentPalette, 16, CRGB::Black);
    // and set every fourth one to white.
    currentPalette[0] = CRGB::White;
    currentPalette[4] = CRGB::White;
    currentPalette[8] = CRGB::White;
    currentPalette[12] = CRGB::White;
    
}

// This function sets up a palette of purple and green stripes.
void SetupPurpleAndGreenPalette()
{
    CRGB purple = CHSV( HUE_PURPLE, 255, 255);
    CRGB green  = CHSV( HUE_GREEN, 255, 255);
    CRGB black  = CRGB::Black;
    
    currentPalette = CRGBPalette16(
                                   green,  green,  black,  black,
                                   purple, purple, black,  black,
                                   green,  green,  black,  black,
                                   purple, purple, black,  black );
}


// This example shows how to set up a static color palette
// which is stored in PROGMEM (flash), which is almost always more
// plentiful than RAM.  A static PROGMEM palette like this
// takes up 64 bytes of flash.
const TProgmemPalette16 myRedWhiteBluePalette_p PROGMEM =
{
    CRGB::Red,
    CRGB::Gray, // 'white' is too bright compared to red and blue
    CRGB::Blue,
    CRGB::Black,
    
    CRGB::Red,
    CRGB::Gray,
    CRGB::Blue,
    CRGB::Black,
    
    CRGB::Red,
    CRGB::Red,
    CRGB::Gray,
    CRGB::Gray,
    CRGB::Blue,
    CRGB::Blue,
    CRGB::Black,
    CRGB::Black
};



// Additional notes on FastLED compact palettes:
//
// Normally, in computer graphics, the palette (or "color lookup table")
// has 256 entries, each containing a specific 24-bit RGB color.  You can then
// index into the color palette using a simple 8-bit (one byte) value.
// A 256-entry color palette takes up 768 bytes of RAM, which on Arduino
// is quite possibly "too many" bytes.
//
// FastLED does offer traditional 256-element palettes, for setups that
// can afford the 768-byte cost in RAM.
//
// However, FastLED also offers a compact alternative.  FastLED offers
// palettes that store 16 distinct entries, but can be accessed AS IF
// they actually have 256 entries; this is accomplished by interpolating
// between the 16 explicit entries to create fifteen intermediate palette
// entries between each pair.
//
// So for example, if you set the first two explicit entries of a compact 
// palette to Green (0,255,0) and Blue (0,0,255), and then retrieved 
// the first sixteen entries from the virtual palette (of 256), you'd get
// Green, followed by a smooth gradient from green-to-blue, and then Blue.

void findreplace(char* ptr, char c1, char c2) {

    while (1) {
      if (*ptr == '\0')
        return;
      if (*ptr == c1)
        *ptr=c2;
      ptr++;
    }
}

void setup() {

    USE_SERIAL.begin(115200);
    USE_SERIAL.println();

    for(uint8_t t = 4; t > 0; t--) {
        USE_SERIAL.printf("[SETUP] Wait for %d second(s)\n", t);
        USE_SERIAL.flush();
        delay(1000);
    }

    setupWifi();
    setupLED();
    setupAccelerometer();
    setupTemp();
}


uint8_t order = '0';

void loop() {

    USE_SERIAL.print("[MAIN] begin...\n");

    //LED
    ChangePalettePeriodically();
    static uint8_t startIndex = 0;
    startIndex++;
    FillLEDsFromPaletteColors(startIndex);
    
    FastLED.show();
    FastLED.delay(1000 / UPDATES_PER_SECOND);
    // end LED

    if((wifiMulti.run() == WL_CONNECTED)) {

        HTTPClient http;
        char urlFormated[400];

        switch (order) {
          
          case '0':   // send accelerometer
            char  x[8],y[8],z[8];
    
            lis.read();
            lis.getEvent(&event);
    
            dtostrf(event.acceleration.x, 7, 2, x);
            dtostrf(event.acceleration.y, 7, 2, y);
            dtostrf(event.acceleration.x, 7, 2, z);
    
            sprintf(urlFormated,"http://%s%s?data=acc%%3B%d%%3B%d%%3B%d%%3B%s%%3B%s%%3B%s\0",SERVER,PATH,lis.x,lis.y,lis.z,x,y,z);
            findreplace(urlFormated,' ','_');   // no space in URL
            break;
            
          case '1':   // send temperature pressure
            char  temp[8],pres[8];

            sensors_event_t temp_event, pressure_event;
            bmp_temp->getEvent(&temp_event);
            bmp_pressure->getEvent(&pressure_event);

            dtostrf(temp_event.temperature, 7, 2, temp);
            dtostrf(pressure_event.pressure, 7, 2, pres);

            sprintf(urlFormated,"http://%s%s?data=temp%%3B%s%%3B%s\0",SERVER,PATH,temp,pres);
            findreplace(urlFormated,' ','_');   // no space in URL
            break;

          default:
            sprintf(urlFormated,"http://%s%s?data=err%%3Bfound nothing to do\0",SERVER,PATH);
            findreplace(urlFormated,' ','_');   // no space in URL
            break;
        }

        USE_SERIAL.print("[HTTP] begin...\n");

        USE_SERIAL.print("[HTTP] url: ");
        USE_SERIAL.print(urlFormated);
        USE_SERIAL.print("\n");

        http.begin(urlFormated); //HTTP

        USE_SERIAL.print("[HTTP] GET...\n");
        // start connection and send HTTP header
        int httpCode = http.GET();

        // httpCode will be negative on error
        if(httpCode > 0) {
            // HTTP header has been send and Server response header has been handled
            USE_SERIAL.printf("[HTTP] GET... code: %d\n", httpCode);

            // file found at server
            if(httpCode == HTTP_CODE_OK) {
                String payload = http.getString();
                USE_SERIAL.println(payload);
                order=payload.c_str()[0];
            }
        } else {
            USE_SERIAL.printf("[HTTP] GET... failed, error: %s\n", http.errorToString(httpCode).c_str());
        }

        http.end();
    }

    USE_SERIAL.print("[MAIN] end.\n");

    delay(1000);
}

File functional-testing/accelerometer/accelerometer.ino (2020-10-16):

// Basic demo for accelerometer readings from Adafruit LIS3DH

#include <Wire.h>
#include <SPI.h>
#include <Adafruit_LIS3DH.h>
#include <Adafruit_Sensor.h>


// I2C
Adafruit_LIS3DH lis = Adafruit_LIS3DH();

void setup(void) {
  Serial.begin(115200);
  while (!Serial) delay(10);     // will pause Zero, Leonardo, etc until serial console opens

  Serial.println("LIS3DH test!");

  if (! lis.begin(0x19)) {   // change this to 0x19 for alternative i2c address
    Serial.println("Couldnt start");
    while (1) yield();
  }
  Serial.println("LIS3DH found!");

  lis.setRange(LIS3DH_RANGE_4_G);   // 2, 4, 8 or 16 G!

  Serial.print("Range = "); Serial.print(2 << lis.getRange());
  Serial.println("G");

  // lis.setDataRate(LIS3DH_DATARATE_50_HZ);
  Serial.print("Data rate set to: ");
  switch (lis.getDataRate()) {
    case LIS3DH_DATARATE_1_HZ: Serial.println("1 Hz"); break;
    case LIS3DH_DATARATE_10_HZ: Serial.println("10 Hz"); break;
    case LIS3DH_DATARATE_25_HZ: Serial.println("25 Hz"); break;
    case LIS3DH_DATARATE_50_HZ: Serial.println("50 Hz"); break;
    case LIS3DH_DATARATE_100_HZ: Serial.println("100 Hz"); break;
    case LIS3DH_DATARATE_200_HZ: Serial.println("200 Hz"); break;
    case LIS3DH_DATARATE_400_HZ: Serial.println("400 Hz"); break;

    case LIS3DH_DATARATE_POWERDOWN: Serial.println("Powered Down"); break;
    case LIS3DH_DATARATE_LOWPOWER_5KHZ: Serial.println("5 Khz Low Power"); break;
    case LIS3DH_DATARATE_LOWPOWER_1K6HZ: Serial.println("16 Khz Low Power"); break;
  }
}

void loop() {
  lis.read();      // get X Y and Z data at once
  // Then print out the raw data
  Serial.print("X:  "); Serial.print(lis.x);
  Serial.print("  \tY:  "); Serial.print(lis.y);
  Serial.print("  \tZ:  "); Serial.print(lis.z);

  /* Or....get a new sensor event, normalized */
  sensors_event_t event;
  lis.getEvent(&event);

  /* Display the results (acceleration is measured in m/s^2) */
  Serial.print("\t\tX: "); Serial.print(event.acceleration.x);
  Serial.print(" \tY: "); Serial.print(event.acceleration.y);
  Serial.print(" \tZ: "); Serial.print(event.acceleration.z);
  Serial.println(" m/s^2 ");

  Serial.println();

  delay(200);
}

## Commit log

2020-10-16 add schematics and testfiles
2020-10-16 add layer schematics
2020-11-03 add stressTest app to validate the board
2020-11-05 adding print image
    [fortithing-v2.scad, fortithing-v2.stl]
